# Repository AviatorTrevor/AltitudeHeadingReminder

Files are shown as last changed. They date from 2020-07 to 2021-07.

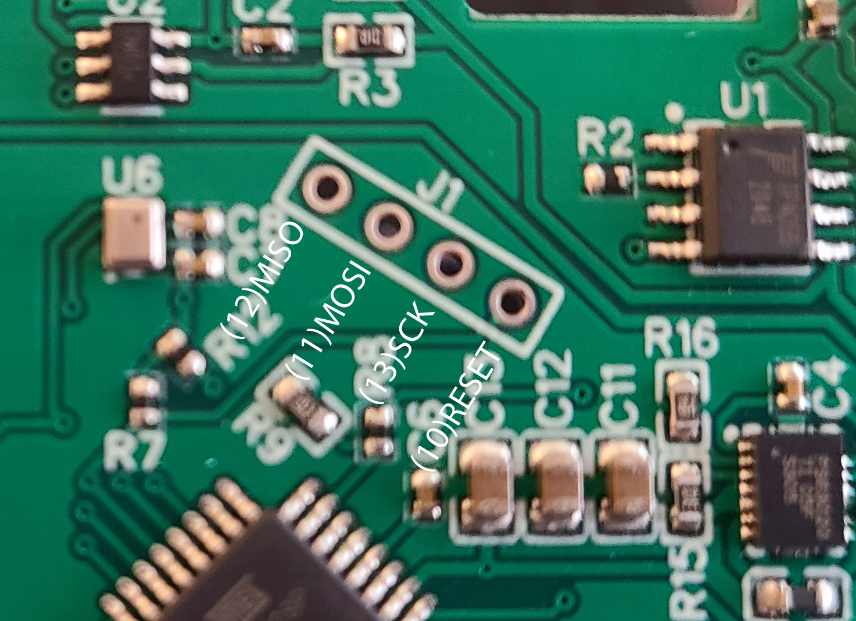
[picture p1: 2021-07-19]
Datasheets and Documents/Bootloader Pins.jpg

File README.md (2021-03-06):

# AltitudeHeadingReminder

Free "EasyEDA" software is needed to view and modify the schematic and PCB design.

Free "openScade" software is needed to view the 3D model of the case

Arduino libraries are modifications of libraries freely found on the web. Those libraries need to be loaded into Arduino in order to compile. The correct type of Arduino and COM port needs to be configured in the Arduino configuration menus before code can be loaded. Because this project runs on a custom PCB board, you need to use the 4 pins on the board for loading a bootloader that has settings to use the onboard 8MHz clock, since there is no external resonator for the clock. Once the bootloader is loaded, you can use the 6-pin FTDI to upload the software using an FTDI adapter.

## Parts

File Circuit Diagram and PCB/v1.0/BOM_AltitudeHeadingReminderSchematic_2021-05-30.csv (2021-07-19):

ID | Name | Designator | Footprint | Quantity | Manufacturer Part | Manufacturer | Supplier | Supplier Part | Price | LCSC Assembly | JLCPCB SMD | Assembly Type | Paste Type
1 | 10uF | C1,C9,C10 | C0402 | 3 | CL05A106MQ5NUNC | SAMSUNG | LCSC | C15525 | 0.0095 | Yes
2 | 100nF | C2,C4,C5,C6,C7,C8 | C0402 | 6 | CL05B104KO5NNNC | SAMSUNG | LCSC | C1525 | 0.0016 | Yes
3 | 22uF | C3,C11,C12,C13,C14,C15,C16 | C0805 | 7 | CL21A226MAQNNNE | SAMSUNG | LCSC | C45783 | 0.038 | Yes
4 | SS34 | D1 | SMA(DO-214AC) | 1 | SS34 |  | LCSC | C8678 | 0.0454
5 | 22uH | L1 | L0805 | 1 | SDFL2012T220KTF | Sunlord | LCSC | C32375 | 0.0343 | Yes
6 | 1.5uH | L2 | L0603 | 1 | MLF1608A1R5JT000 | TDK | LCSC | C87514 | 0.0356 | Yes
7 | FS8205 | Q1 | SOT-23-6 | 1 | FS8205 | FORTUNE | LCSC | C32254 | 0.1688
8 | MMBT3906LT1G | Q2,Q3 | SOT-23-3_L2.9-W1.3-P1.90-LS2.4-BR | 2 | MMBT3906LT1G | ON | LCSC | C53444 | 0.0151 | Yes | Yes | smtWeld | expand
9 | MMBT3904_C181119 | Q4 | SOT-23-3_L2.9-W1.6-P1.90-LS2.8-BR | 1 | MMBT3904 | Hottech | LCSC | C181119 | 0.0101 | Yes | Yes | smtWeld | expand
10 | KT-0603R | R | LED0603-R-RD | 1 | KT-0603R | KENTO | LCSC | C2286 | 0.0059 | Yes
11 | 100 | R3 | R0603 | 1 | 0603WAF1000T5E | UniOhm | LCSC | C22775 | 0.0017 | Yes
12 | 2K | R2,R4 | R0402 | 2 | 0402WGF2001TCE | UniOhm | LCSC | C4109 | 0.0007 | Yes
13 | 39K | R5 | R0402 | 1 | 0402WGF3902TCE | UniOhm | LCSC | C25783 | 0.0008 | Yes
14 | 1K | R1,R6 | R0402 | 2 | 0402WGF1001TCE | UniOhm | LCSC | C11702 | 0.0008 | Yes
15 | 30K | R9 | R0603 | 1 | 0603WAF3002T5E | UniOhm | LCSC | C22984 | 0.0017 | Yes
16 | 10K | R7,R8,R10,R11,R12,R13 | R0402 | 6 | 0402WGF1002TCE | UniOhm | LCSC | C25744 | 0.0008 | Yes
17 | 1M | R15 | R0603 | 1 | 0603WAF1004T5E | UniOhm | LCSC | C22935 | 0.0018 | Yes
18 | 180K | R16 | R0603 | 1 | 0603WAF1803T5E | UniOhm | LCSC | C22827 | 0.0017 | Yes
19 | TP4056 | U1 | ESOP-8_L4.9-W3.9-P1.27-LS6.0-BL-EP | 1 | TP4056 | TOPPOWER | LCSC | C16581 | 0.2164 | Yes
20 | FS312F-G | U2 | SOT-23-6 | 1 | DW01+G | FORTUNE | LCSC | C14213 | 0.1103
21 | MT3608 | U3 | SOT-23-6 | 1 | MT3608 | LCSC | LCSC | C84817 | 0.1423
22 | ATMEGA328P-AU | U5 | TQFP-32_L7.0-W7.0-P0.80-LS9.0-BL | 1 | ATMEGA328P-AU | MICROCHIP | LCSC | C14877 | 5.4962 | Yes
23 | SPL06-001 | U6 | SENSOR-SMD_SPL06-001 | 1 | SPL06-001 | Goertek(歌尔) | LCSC | C2684428 | 0.9605
24 | TPS63020DSJR | U7 | VSON-14_L4.0-W3.0-P0.50-BL | 1 | TPS63020DSJR | TI | LCSC | C15483 | 2.9538 | Yes
25 | TYPEC-304S-ACP16 | USB1 | USB-C-SMD_TYPEC-304S-ACP16 | 1 | TYPEC-304S-ACP16 | XUNPU | LCSC | C720630 | 0.1797 |  |  | smtWeld | expand

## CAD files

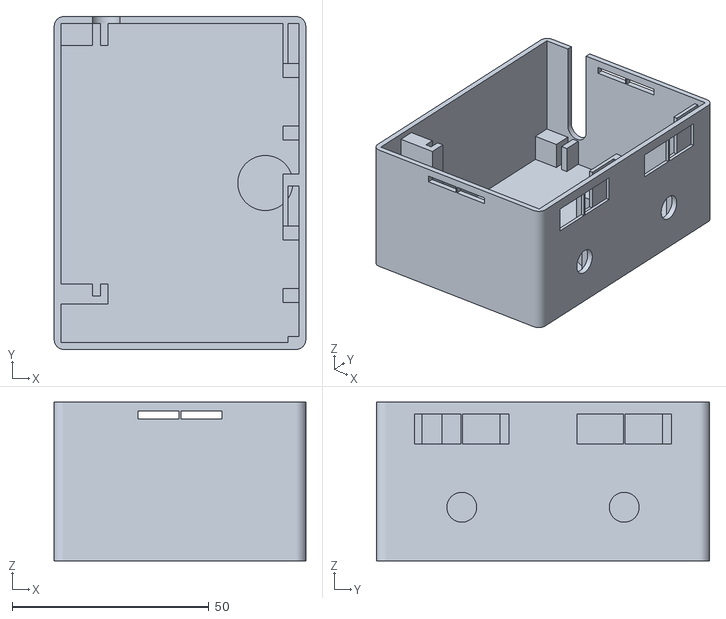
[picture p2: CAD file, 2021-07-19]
Case/Prints/Main.stl
64.0 x 84.7 x 40.4

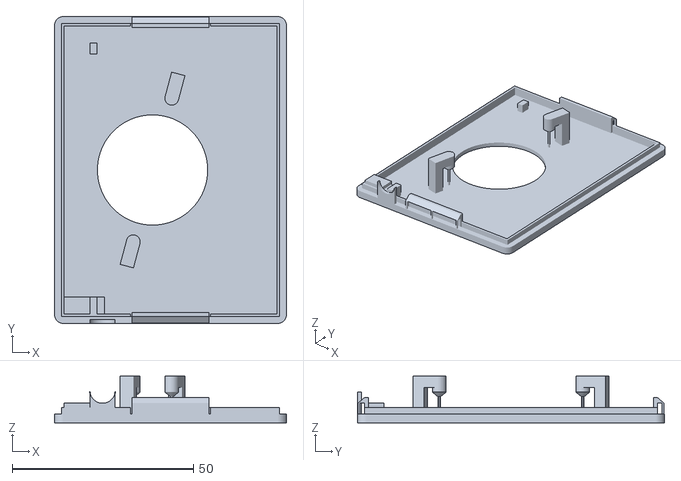
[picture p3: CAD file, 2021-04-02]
Case/Prints/Top.stl
64.0 x 84.7 x 12.8

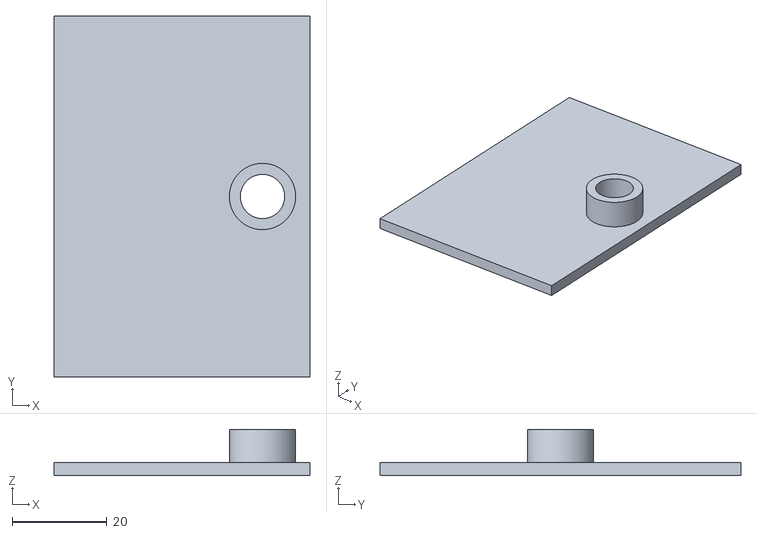
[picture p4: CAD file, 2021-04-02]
Case/Prints/MountingPlate.stl
54.0 x 76.2 x 9.80

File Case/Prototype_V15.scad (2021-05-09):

//everything is in units of millimeters
resolution = 0.35;

//variables to keep in-sync with the other scad file.
pcbBoardHeight = 36.9;
pcbBoardWidth = 69.35;
innerLipHeightAboveOuterLipHeight = resolution * 5;
mainShellThickness = 5 * resolution;
mainDepth = 64;
mainWidth = 84.7;
mainHeight = pcbBoardHeight + mainShellThickness + innerLipHeightAboveOuterLipHeight;
caseCornerRadius = 2.5;
cylinderFragments = 70;

batteryThicknessAndSpacing = 8;
pcbBoardThickness = 2;
pcbMountingWallThickness = 2;
pcbBottomRightWidth = 5.6;
pcbLidTopRightZAxisHeight = 1.2;
pcbOffsetX = mainShellThickness + batteryThicknessAndSpacing;
pcbOffsetY = mainWidth - mainShellThickness - pcbBoardWidth;
pcbBottomRightHeight = 8;
pcbLeftWidth = 3.1;

usbSlotWidth = 7;
usbSlotHeight = 27;
usbSlotXoffset = pcbOffsetX; //offset above mainShellThickness
usbSlotZoffset = 8.5 + usbSlotWidth / 2;

lidThickness = resolution * 4; //z-axis
lidLipWidth = resolution * 2;  //x & y axis thickness of the lip/wall
outerLipHeight = resolution * 5; //height above lidThickness
innerLipHeight = outerLipHeight + innerLipHeightAboveOuterLipHeight; //height above lidThickness
spacingForLidLipFromCaseWall = resolution / 2;
margin = mainShellThickness + lidLipWidth + spacingForLidLipFromCaseWall;
marginFromSnapJointCutaway = resolution;

lidSnapJointProtrusionHeight = 1.5;
lidSnapJointWidth = mainDepth / 3;
lidSnapJointProtrusionLength = mainShellThickness;
lidSnapJointOffsetFromTop = 3;
extensionBeyondOuterLipForSnapJoint = 2;

frontFaceThickness = 3 * resolution;
displayThickness = 3.5; //this is used for the snap-fit mechanism 
displayBackLegThickness = 1.2;
knobAndDisplaySupportWallDepth = displayThickness  - (mainShellThickness - frontFaceThickness) + displayBackLegThickness;

//keep in-sync with the mounting plate file
mountingHoleRadius = 4.5;
mountingQuarterInchRadius = 3.9;
mountingPillarRadius = mountingHoleRadius + 2.5;
mountingHoleHeight = 9.8;
mountingTransitionHeight = 4;
mountingQuarterInchCylinderHeight = mainHeight - mountingHoleHeight - mountingTransitionHeight - 16;
mountingPillarHeight = mainHeight - 14.5;

supportBracketThickness = 0.45;

//////////////////////////////////////////////////////////////////////
//////////////////////////////////////////////////////////////////////
//////////////////////////////////////////////////////////////////////
displayEdgeBuffer = 0.8;
displayWidth = 22.5 + displayEdgeBuffer*2;
displayDepth = mainShellThickness;
displayHeight = 6 + displayEdgeBuffer*2;
displayYOffset = 8.6;
displayIndentWidth = 38.5;
displayIndentHeight = 12.4;
displayIndentYOffsetFromDisplayY = -5.7 - displayEdgeBuffer;
displayIndentZOffsetFromDisplayZ = -2.7 - displayEdgeBuffer;
displayTopOffset = displayIndentHeight + displayIndentZOffsetFromDisplayZ + innerLipHeightAboveOuterLipHeight;
displayPinsYaxisWidth = 2.7;
knobAndDisplaySupportWallWidth = 3.5;
displaySideRetainingPillarThickness = displayThickness - (mainShellThickness - frontFaceThickness);
knobHoleYoffset = displayYOffset + (displayWidth / 2);
knobHoleZoffset = mainShellThickness + 11.9;
knobHoleRadius = 3.8;
knobHoleDepth = mainShellThickness + knobAndDisplaySupportWallDepth;
knobIndentSquareSideLength = 12.4;
knobHookZaxisOffset = 5.1;
knobHookYaxisWidth = 2.2;
knobHookXaxisDepth = knobHoleDepth - resolution*1.5;
knobHookZaxisHeight = 1.7;
gapBetweenTopOfKnobCutoutAndBottomOfDisplayCutout = (mainHeight - displayTopOffset + displayIndentZOffsetFromDisplayZ) - (knobHoleZoffset + knobIndentSquareSideLength/2);
mountingHoleX = mainDepth - mountingPillarRadius - 3.3;


//MODULE snap joint for lid
module createLeftSideLidSnapJoint()
{
  translate([mainDepth/2 - lidSnapJointWidth/2, 0, mainHeight - lidSnapJointOffsetFromTop - lidSnapJointProtrusionHeight + 0.2]) { //NOTE: keep 0.2 in sync
    cube([lidSnapJointWidth, mainShellThickness, lidSnapJointProtrusionHeight + 0.5]);
  };
};

module cutoutLeftKnobStuff() {
  //left knob
  translate([mainDepth - knobHoleDepth, mainWidth/2 - knobHoleYoffset, knobHoleZoffset]) {
    rotate([0,90,0]) {
      cylinder(knobHoleDepth,knobHoleRadius,knobHoleRadius,$fn=cylinderFragments);
    };
  };
  //left knob hook slot
  translate([mainDepth - knobHoleDepth, mainWidth/2 - knobHoleYoffset - knobHookYaxisWidth / 2, knobHoleZoffset - knobHookZaxisOffset - knobHookZaxisHeight]) {
    cube([knobHookXaxisDepth, knobHookYaxisWidth, knobHookZaxisHeight]);
  };
};
module cutoutRightKnobStuff() {
  //right knob
  translate([0,mainWidth,0]) {
    mirror([0,1,0]) {
      cutoutLeftKnobStuff();
    };
  };
};

module cutoutLeftDisplayIndent() {
  //left display indent to make the wall thinner
  translate([mainDepth - displayDepth, mainWidth/2 - displayWidth - displayYOffset + displayIndentYOffsetFromDisplayY, mainHeight - displayTopOffset + displayIndentZOffsetFromDisplayZ]) {
    cube([mainShellThickness - frontFaceThickness, displayIndentWidth, displayIndentHeight]);
  };
  //extra cutout for pins
  translate([mainDepth - displayDepth, mainWidth/2 - displayWidth - displayYOffset + displayIndentYOffsetFromDisplayY, mainHeight - displayTopOffset + displayIndentZOffsetFromDisplayZ]) {
    cube([mainShellThickness - resolution*1.5, displayPinsYaxisWidth, displayIndentHeight]);
  };
};

module cutoutRightDisplayIndent() {
  //right display indent to make the wall thinner
  translate([mainDepth - displayDepth, mainWidth/2 + displayYOffset + displayIndentYOffsetFromDisplayY, mainHeight - displayTopOffset + displayIndentZOffsetFromDisplayZ]) {
    cube([mainShellThickness - frontFaceThickness, displayIndentWidth, displayIndentHeight]);
  };
  //extra cutout for pins
  translate([mainDepth - displayDepth, mainWidth/2 + displayYOffset + displayIndentYOffsetFromDisplayY, mainHeight - displayTopOffset + displayIndentZOffsetFromDisplayZ]) {
    cube([mainShellThickness - resolution*1.5, displayPinsYaxisWidth, displayIndentHeight]);
  };
};
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

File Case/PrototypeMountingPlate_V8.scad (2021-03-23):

//everything is in units of millimeters
resolution = 0.35;

//variables to keep in-sync with the other scad file
mainShellThickness = 5 * resolution;
mainDepth = 57;
mainWidth = 91;
mainHeight = 37 + mainShellThickness;
caseCornerRadius = 2.5;
cylinderFragments = 70;

//keep in-sync with the main case file
mountingHoleRadius = 4.45;
mountingPillarRadius = mountingHoleRadius + 1.5;
mountingHoleHeight = 8.68;
mountingPillarHeight = mountingHoleHeight + 0.5;

plateDepth = mainDepth / 1.5;
plateWidth = mainWidth / 1.5;
plateThickness = mountingPillarHeight;
plateHoleRadius = mountingHoleRadius + resolution / 2;
plateMountingHoleX = plateDepth - plateThickness - mountingHoleRadius - 3.3; //keep aligned with mountingHoleX variable

difference() {
    cube([plateDepth, plateWidth, plateThickness]);
    
    //bottom mounting hole
    translate([plateMountingHoleX, plateWidth/2, 0]) {
      cylinder(plateThickness, plateHoleRadius, plateHoleRadius, $fn=cylinderFragments);
    };
};

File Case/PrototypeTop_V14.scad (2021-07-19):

//everything is in units of millimeters
resolution = 0.35;

//variables to keep in-sync with the other scad file
pcbBoardHeight = 36.9;
pcbBoardWidth = 69.35;
innerLipHeightAboveOuterLipHeight = resolution * 5;
mainShellThickness = 5 * resolution;
mainDepth = 64;
mainWidth = 84.7;
mainHeight = pcbBoardHeight + mainShellThickness + innerLipHeightAboveOuterLipHeight;
caseCornerRadius = 2.5;
cylinderFragments = 70;

batteryThicknessAndSpacing = 8;
pcbBoardThickness = 2;
pcbMountingWallThickness = 2;
pcbBottomRightWidth = 5.6;
pcbLidTopRightZAxisHeight = 1.2;
pcbOffsetX = mainShellThickness + batteryThicknessAndSpacing;
pcbOffsetY = mainWidth - mainShellThickness - pcbBoardWidth;
pcbBottomRightHeight = 8;
pcbLeftWidth = 3.1;

usbSlotWidth = 7;
usbSlotHeight = 27;
usbSlotXoffset = pcbOffsetX; //offset above mainShellThickness
usbSlotZoffset = 8.5 + usbSlotWidth / 2;

lidThickness = resolution * 4; //z-axis
lidLipWidth = resolution * 2;  //x & y axis thickness of the lip/wall
outerLipHeight = resolution * 3; //height above lidThickness
innerLipHeight = outerLipHeight + innerLipHeightAboveOuterLipHeight; //height above lidThickness
spacingForLidLipFromCaseWall = resolution / 2;
margin = mainShellThickness + lidLipWidth + spacingForLidLipFromCaseWall;
marginFromSnapJointCutaway = resolution;

lidSnapJointProtrusionHeight = 1.5;
lidSnapJointWidth = mainDepth / 3;
lidSnapJointProtrusionLength = mainShellThickness;
lidSnapJointOffsetFromTop = 3;
extensionBeyondOuterLipForSnapJoint = 2;

frontFaceThickness = 3 * resolution;
displayThickness = 3.5; //this is used for the snap-fit mechanism 
displayBackLegThickness = 1.2;
knobAndDisplaySupportWallDepth = displayThickness  - (mainShellThickness - frontFaceThickness) + displayBackLegThickness;

lidSnapJointHingeThickness = outerLipHeight * 0.4; //has to be quite a bit smaller than outerLipHeight
lidSnapJointLegThickness = resolution * 3;
lidSnapJointCutoutGapFromEdge = resolution * 2;

outerLipWidth = mainShellThickness + spacingForLidLipFromCaseWall;

//////////////////////////////////////////////////////////////////////
//////////////////////////////////////////////////////////////////////
//////////////////////////////////////////////////////////////////////

buzzerRadius = 30.4 / 2; //30.4 is diameter
buzzerScrewOffset = 20.5; //20.5 mm from center of buzzer hole to center of screw hole
buzzerScrewRadius = 1.9;
buzzerX = pcbOffsetX + pcbBoardThickness + buzzerRadius + 0.1;
buzzerY = mainWidth / 2;
buzzerScrewHeight = 5;
buzzerScrewHeightForBaseHolding = 2.5;
buzzerPlatformOffset = 3.8; //offset from center of cylinder to edge of wall to clear the buzzer
buzzerPlatformThickness = 9 * resolution;
buzzerScrewPylonZOffset = -0.8; //distance from the lid to fit the buzzer into the slot

screwHeadCylinderRadius = 1.8;
screwHeadSinkDepth = lidThickness * 0.6;

snapHook3dPrintingSupportPillarThickness = resolution * 1.4;
buzzer3dPrintingSupportPillarThicknessRadius = resolution * 0.9;

module rotate_about_pt(z, y, pt) {
    translate(pt)
        rotate([0, y, z])
            translate(-pt)
                children();   
}

module innerCube() {
  translate([margin, margin, lidThickness]) {
    cube([mainDepth - margin*2, mainWidth - margin*2, innerLipHeight]);
  };
};

module cutOutLeftSideForHinge() {
  //cut away the inner wall for left side snap fit stuff + buffer on either side
  translate([mainDepth/2 - lidSnapJointWidth/2 - marginFromSnapJointCutaway, outerLipWidth, lidThickness]) {
    cube([lidSnapJointWidth + marginFromSnapJointCutaway*2, lidLipWidth, innerLipHeight]);
  };
};

module leftBuzzerPlatform() {
  translate([buzzerX, buzzerY - buzzerScrewOffset, lidThickness + buzzerScrewHeight - buzzerScrewPylonZOffset]) {
    cylinder(buzzerScrewHeightForBaseHolding/2, buzzerScrewRadius * 0.2, buzzerScrewRadius, $fn=cylinderFragments);
  };
  translate([buzzerX, buzzerY - buzzerScrewOffset, lidThickness + buzzerScrewHeight + buzzerScrewHeightForBaseHolding/2 - buzzerScrewPylonZOffset]) {
    cylinder(buzzerScrewHeightForBaseHolding/2 + buzzerPlatformThickness, buzzerScrewRadius, buzzerScrewRadius, $fn=cylinderFragments);
  };
  //3D printed support for screw mount
  translate([buzzerX, buzzerY - buzzerScrewOffset, lidThickness]) {
    cylinder(buzzerScrewHeight - buzzerScrewPylonZOffset, buzzer3dPrintingSupportPillarThicknessRadius, buzzer3dPrintingSupportPillarThicknessRadius, $fn=cylinderFragments);
  };
  
  //horizontal platform to hold buzzer
  translate([buzzerX - buzzerScrewRadius, buzzerY - buzzerScrewOffset - buzzerPlatformOffset - buzzerPlatformThickness, lidThickness + buzzerScrewHeight + buzzerScrewHeightForBaseHolding - buzzerScrewPylonZOffset]) {
    cube([2*buzzerScrewRadius, buzzerPlatformOffset + buzzerPlatformThickness,buzzerPlatformThickness]);
  };
  //vertical platform to mount the horizontal platform
  translate([buzzerX - buzzerScrewRadius, buzzerY - buzzerScrewOffset - buzzerPlatformOffset - buzzerPlatformThickness, lidThickness]) {
    cube([2*buzzerScrewRadius, buzzerPlatformThickness, buzzerScrewHeight + buzzerScrewHeightForBaseHolding - buzzerScrewPylonZOffset]);
  };
};

difference() {
  union() {
    //top cover of the lid
    cube([mainDepth, mainWidth, lidThickness]);
      
    //outer lip
    difference() {
      translate([0, 0, lidThickness]) {
        cube([mainDepth, mainWidth, outerLipHeight]);
      };
      translate([outerLipWidth, outerLipWidth, lidThickness]) {
        cube([mainDepth - outerLipWidth*2, mainWidth - outerLipWidth*2, outerLipHeight]);
      };
    };
    
    //add rails for better seating
    difference() {
      translate([margin - lidLipWidth, margin - lidLipWidth, lidThickness]) {
        cube([mainDepth - margin*2 + lidLipWidth*2, mainWidth - margin*2 + lidLipWidth*2, innerLipHeight]);
      };
      innerCube();
    };
  };

  //cutting out the inside to save on plastic used
  innerCube();
  
  //cutting away room at the corner of the lip to make room for the cylinders where screws go.
  //rear-left
  translate([0, 0, 0]) {
    cube([caseCornerRadius, caseCornerRadius, lidThickness + outerLipHeight]);
  };
  
  //cutting away room at the corner of the lip to make room for the cylinders where screws go.
  //front-left
  translate([mainDepth - caseCornerRadius, 0, 0]) {
    cube([caseCornerRadius, caseCornerRadius, lidThickness + outerLipHeight]);
  };
  
  //cutting away room at the corner of the lip to make room for the cylinders where screws go.
  //front-right
  translate([mainDepth - caseCornerRadius, mainWidth - caseCornerRadius, 0]) {
    cube([caseCornerRadius, caseCornerRadius, lidThickness + outerLipHeight]);
  };
  
  //cutting away room at the corner of the lip to make room for the cylinders where screws go.
  //rear-right
  translate([0, mainWidth - caseCornerRadius, 0]) {
    cube([caseCornerRadius, caseCornerRadius, lidThickness + outerLipHeight]);
  };
  
  //buzzer alarm hole
  translate([buzzerX, buzzerY, 0]) {
    cylinder(lidThickness, buzzerRadius, buzzerRadius, $fn=cylinderFragments*2);
  };
  
  cutOutLeftSideForHinge();
  translate([0,mainWidth - 0.001,0]) {
    mirror([0,1,0]) {
      cutOutLeftSideForHinge();
    };
  };
};

module snapHook3dPrintingSupportPillarBeneathProtrusion() {
  cube([snapHook3dPrintingSupportPillarThickness, snapHook3dPrintingSupportPillarThickness, lidSnapJointOffsetFromTop]);
};
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

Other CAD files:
Case/Prototype_V1.scad
Case/Old Designs/PrototypeMountingPlate_V1.scad
Case/Old Designs/PrototypeMountingPlate_V2.scad
Case/Old Designs/PrototypeTop_V1.scad
Case/Old Designs/PrototypeTop_V10.scad
Case/Old Designs/PrototypeTop_V11.scad
Case/Old Designs/PrototypeTop_V12.scad
Case/Old Designs/PrototypeTop_V13.scad
Case/Old Designs/PrototypeTop_V2.scad
Case/Old Designs/PrototypeTop_V3.scad
Case/Old Designs/PrototypeTop_V4.scad
Case/Old Designs/PrototypeTop_V5.scad
Case/Old Designs/PrototypeTop_V6.scad
Case/Old Designs/PrototypeTop_V7.scad
Case/Old Designs/PrototypeTop_V8.scad
Case/Old Designs/PrototypeTop_V9.scad
Case/Old Designs/Prototype_V1.scad
Case/Old Designs/Prototype_V10.scad
Case/Old Designs/Prototype_V11.scad
Case/Old Designs/Prototype_V12.scad
Case/Old Designs/Prototype_V13.scad
Case/Old Designs/Prototype_V14.scad
Case/Old Designs/Prototype_V2.scad
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

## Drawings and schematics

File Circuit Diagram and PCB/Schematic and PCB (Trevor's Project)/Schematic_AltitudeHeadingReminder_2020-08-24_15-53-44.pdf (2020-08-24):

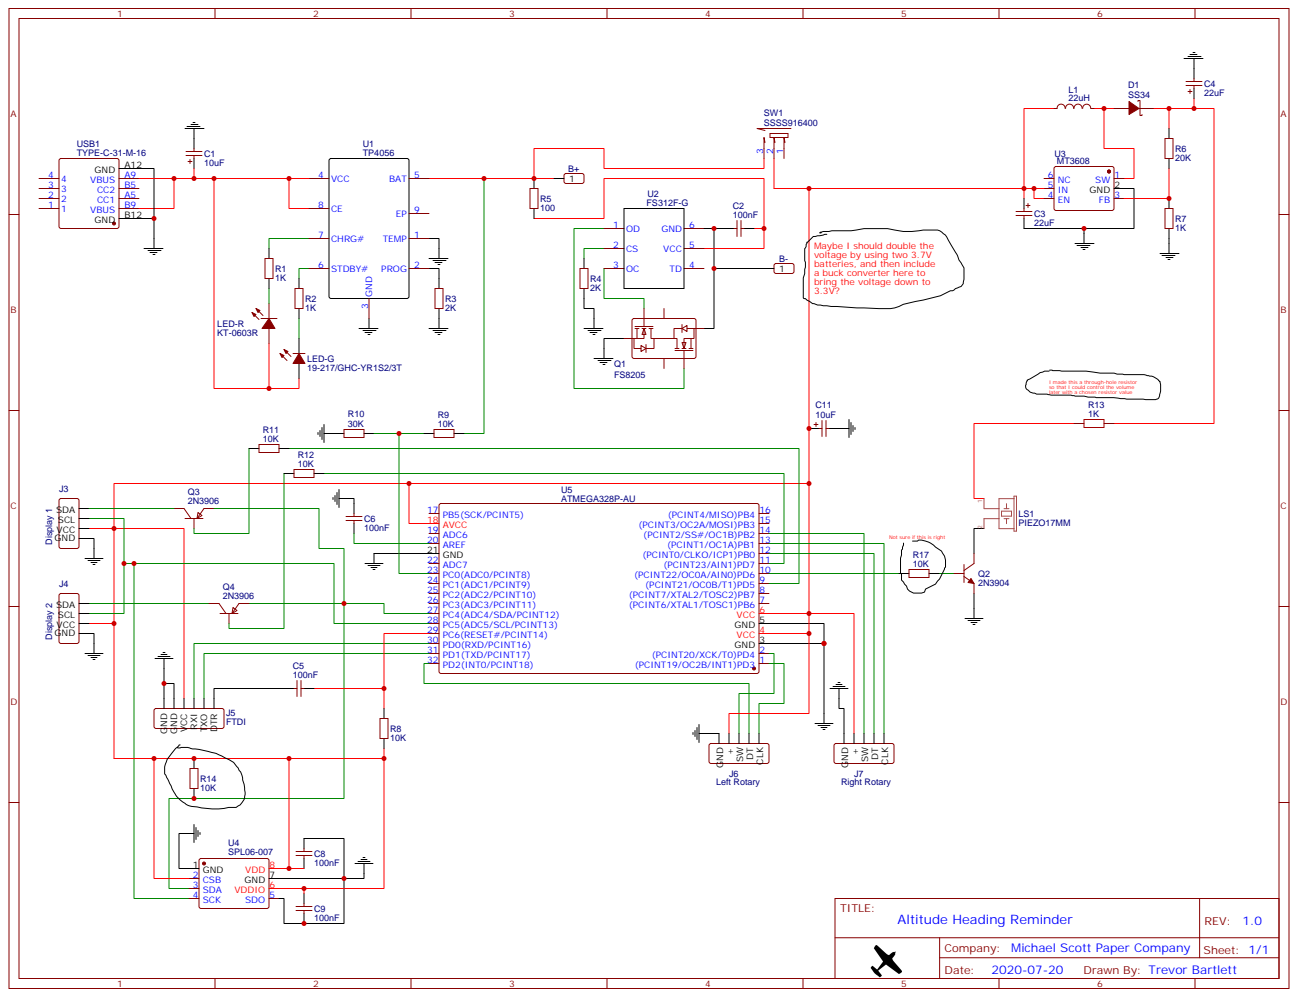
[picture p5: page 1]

Maybe I should double the
voltage by using two 3.7V

batteries, and then include
a buck converter here to
bring the voltage down to

I made this a through-hole resistor
so that I could control the volume
later with a chosen resistor value

Not sure if this is right

Company: Michael Scott Paper Company

Drawn By: Trevor Bartlett

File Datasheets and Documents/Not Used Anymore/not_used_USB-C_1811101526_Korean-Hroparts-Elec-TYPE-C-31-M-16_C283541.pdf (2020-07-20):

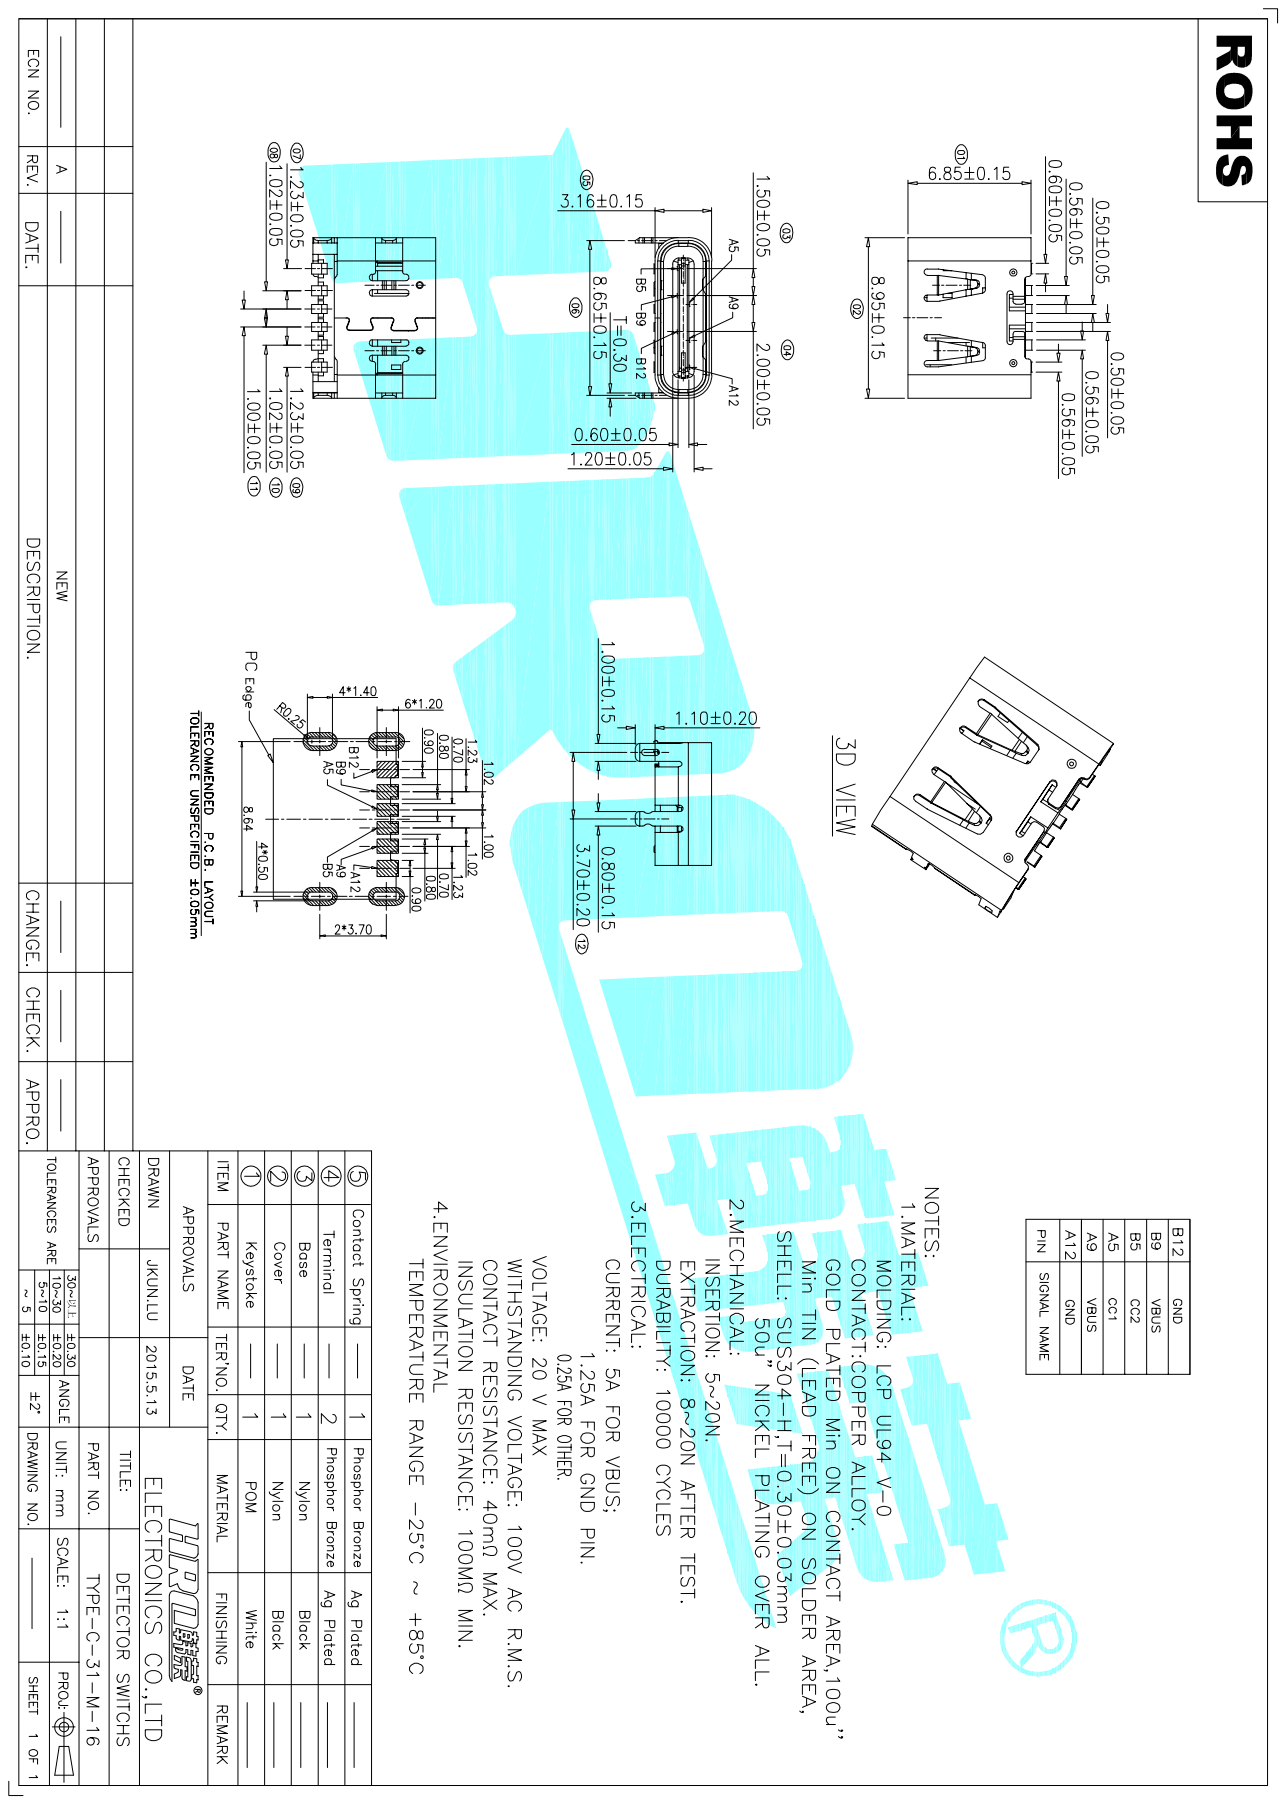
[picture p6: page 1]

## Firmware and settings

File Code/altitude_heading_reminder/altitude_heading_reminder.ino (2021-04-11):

/*
Author: Trevor Bartlett
Email: aviatortrevor@gmail.com

Hardware device to remind pilots of assigned headings, altitudes, IFR procedure minimums, and other features.
The device measures atmospheric pressure to present to the pilot what their altitude is. Cabin altitude can
be slightly different from static pressure used by the aircraft's altimeter, so there is a calibration offset
provided to the user. It also has buzzer feature to alert the pilot of when he/she is approaching their
selected altitude, or departed from it.

*TODO:
*add adjustable altitude-deviation alert?
*create software license - credit for libraries used
*     https://forum.arduino.cc/index.php?topic=175511.0
*     http://www.engblaze.com/microcontroller-tutorial-avr-and-arduino-timer-interrupts/
*     https://learn.adafruit.com/adafruit-gfx-graphics-library/using-fonts
*/
#include <EEPROM.h>
#include <SPL06-007.h>
#include <Wire.h>
#include <Custom_GFX.h>
#include <Custom_SSD1306.h>

#define cAppCodeNumberOfDigits         6
#define cAppCodeOne                    8
#define cAppCodeTwo                    8
#define cAppCodeThree                  1
#define cAppCodeFour                   6
#define cAppCodeFive                   6
#define cAppCodeSix                    6
#define cOneSecond                     1000 //1000 milliseconds = 1 second
#define cOneSecondBeforeOverflow       (unsigned long)(pow(2, sizeof(unsigned long) * 8) - cOneSecond)
#define cTenSeconds                    10000
#define cLeftRotaryTimeoutSeconds      cTenSeconds
#define cFeetInMeters                  3.28084
#define cSeaLevelPressureHPa           1013.25 //standard sea level pressure in millibars
#define cMbInHg                        33.8639
#define cSeaLevelPressureInHg          2992 //standard sea level pressure in inches of mercury (x100)
#define cSeaLevelPressureInHgDouble    29.92
#define cFtLabel                       "ft"
#define cInLabel                       "\""
#define cDegFLabel                     'F'
#define cAltitudeSelectIncrement       100   //ft
#define cAltitudeFineSelectIncrement   10    //ft
#define cAltitudeHighSelectIncrement   1000  //ft
#define cMinimumsSelectIncrement       50    //ft
#define cHighAltitude                  18000 //ft
#define cDefaultSelectedAltitude       10000 //ft
#define cDefaultMinimumsAltitude       1000  //ft
#define cLowestAltitudeSelect          -1000 //ft
#define cHighestAltitudeSelect         60000 //ft
#define cHighestAltitudeAlert          24000 //ft, the pressure sensor will only measure so high. No point in alerting above a certain pressure level
#define cAltimeterSettingInHgMin       2750  //inHg * 100
#define cAltimeterSettingInHgMax       3150  //inHg * 100
#define cAltimeterSettingInHgInterval  1     //inHg
#define cCalibrationOffsetMin          -5000 //ft
#define cCalibrationOffsetMax          5000  //ft
#define cCalibrationOffsetInterval     10    //ft
#define cHeadingSelectIncrement        5     //degrees
#define cDefaultSelectedHeading        360   //degrees
#define cTrueAltitudeRoundToNearestFt  10    //ft

//EEPROM
#define         cSizeOfEeprom                       EEPROM.length() //1024
#define         cEepromWriteDelay                   1200  //milliseconds
#define         cEepromMaxWrites                    100000
#define         cEepromNextAvailableSlot            12
#define         cEepromAltimeterAddr                14
#define         cEepromAltitudeOffsetAddr           16
#define         cEepromPermanentAltitutdeOffsetAddr 18
#define         cEepromSensorModeAddr               20
#define         cEepromScreenDimAddr                22
#define         cEepromScreenOrientationAddr        24
#define         cEepromSelectedAltitudeAddr         26
#define         cEepromSelectedHeadingAddr          28
#define         cEepromSelectedMinimumsAddr         30
#define         cEepromLastAddr                     cEepromSelectedMinimumsAddr
volatile bool   gNeedToWriteToEeprom;

//SPL06-007 Sensor variables
#define    cSensorLoopCycle               2 //2Hz
#define    cSensorLoopPeriod              (cOneSecond / cSensorLoopCycle)
double     gSensorTemperatureDouble;      //farhenheit
enum SensorMode {SensorModeOff, SensorModeSilent, SensorModeOnHide, SensorModeOnShow, cNumberOfSensorModes};
volatile SensorMode gSensorMode;

//Main program variables
double          gTrueAltitudeDouble;
volatile long   gSelectedAltitudeLong;
volatile int    gAltimeterSettingInHgInt;
volatile int    gCalibratedAltitudeOffsetInt;
volatile int    gPermanentCalibratedAltitudeOffsetInt;
volatile int    gSelectedHeadingInt; //degrees
volatile bool   gMinimumsOn;
volatile long   gMinimumsAltitudeLong;
volatile bool   gMinimumsTriggered = true;
volatile bool   gMinimumsSilenced = true;

//Anti-piracy
volatile int    gSelectAppCode = 0;
volatile int    gAppCodeSequence = 0;
bool            gLegitimate = true;

//Buzzer
#define            cAlarm200ToGo                         200  //ft
#define            cAlarm1000ToGo                        1000 //ft
#define            cBuzzPin                              6
#define            cLongBuzzDuration                     1000
#define            cShortBuzzOnDuration                  250
#define            cShortBuzzOffDuration                 100
#define            cMinimumsLongBuzzOnDuration           375
#define            cMinimumsShortBuzzOnDuration          125
#define            cMinimumsBuzzOffDuration              125
#define            cMinimumsOffBetweenCycleDuration      125
#define            cMinimumsNumberOfBeepCylces           5
#define            cUrgentBuzzNumberOfBeeps              3
#define            cDisableAlarmKnobMovementTime         1200
#define            cDisableAlarmAfterAlarmTime           1800
enum BuzzAlarmMode {Climbing1000ToGo, Climbing200ToGo, Descending1000ToGo, Descending200ToGo, AltitudeDeviate, UrgentAlarm, MinimumsAlarm, LongAlarm, AlarmDisabled, DetermineAlarmState};
BuzzAlarmMode      gAlarmModeEnum = AlarmDisabled;
int                gBuzzCountInt;
int                cPowerUpSilence = 7000; //wait 7 seconds after start-up before alarm can begin making sounds. this is so you don't scare anyone with a loud alarm as soon as they start it up at home.

//Minimums
#define            cMinimumsSilencedAutoOnAltitudeDiff   100 //ft
#define            cMinimumsTriggeredAutoOffTime         30000 //30 seconds

//Top-left corner message for low battery or silent mode
#define       cAltMessageInterval 15000 //15 seconds
#define       cAltMessageDuration 1500  //1.5 seconds

//Battery
#define       cBatteryVoltagePin      A0
#define       cBatteryUpdateInterval  3000 //once per 3 seconds
#define       cBatteryAlertLevel      15
int           gBatteryLevel;
bool          gBatteryCharging;
unsigned long gBatteryUpdateTs;
#define       cBatteryCapacityArrayLength   21
#define       cBatteryCapacityArrayInterval 5 //this represents the jump in battery capacity per index in the array
const double  cBatteryCapacity[2][cBatteryCapacityArrayLength] = {
  2.40, 3.41, 3.48, 3.54, 3.58, 3.62, 3.67, 3.71, 3.76, 3.79, 3.82, 3.84, 3.87, 3.91, 3.94, 3.98, 4.01, 4.03, 4.06, 4.09, 4.15,
     0,    5,   10,   15,   20,   25,   30,   35,   40,   45,   50,   55,   60,   65,   70,   75,   80,   85,   90,   95,  100
};

//Timing control
unsigned long          gNextSensorReadyTs;
unsigned long          gNextBuzzTs;
unsigned long          gLastAlarmTs; //this value disables the alarm temporarily just at start-up so people's ears aren't blown when they power it on.
unsigned long          gTimerStartTs;
unsigned long          gMinimumsTriggeredTs;
volatile unsigned long gLeftButtonPressedTs;
volatile unsigned long gRightButtonPressedTs;
volatile unsigned long gLastRightRotaryActionTs;
volatile unsigned long gLastMinimumsAltitudeTs;
volatile unsigned long gLeftRotaryReleaseTs;
volatile unsigned long gRightRotaryReleaseTs;
volatile unsigned long gEepromSaveNeededTs;
volatile unsigned long gLastRotaryActionTs;

//Display
#define cPinLeftDisplayControl  5
#define cPinRightDisplayControl 7
#define CONTROL_ON       LOW
#define CONTROL_OFF      HIGH
#define cOledAddr        0x3C
#define cOledWidth       128
#define cOledHeight      32
#define cOledReset       4
#define cLabelTextSize   1
#define cLabelTextYpos   1
#define cReadoutTextSize 3
#define cReadoutTextYpos 10
Custom_SSD1306 gOled(cOledWidth, cOledHeight, &Wire, cOledReset);
volatile bool gOledDim = false;
volatile bool gDeviceFlipped = false;
volatile bool gUpdateLeftScreen = true;
volatile bool gUpdateRightScreen = true;
bool gFlashLeftScreen = false;
bool gFlashRightScreen = false;

char gDisplayTopContent[20];
char gDisplayBottomContent[10];

//Cursor control
enum Cursor {
    CursorSelectHeading,
    CursorSelectAltimeter,
    CursorSelectMinimumsOn,
    CursorSelectMinimumsAltitude,
    CursorSelectTimer,
    CursorSelectBrightness, //starting here, values won't stay on the screen for more than a few seconds unless there is a rotary action
    CursorSelectOffset,
    CursorSelectSensor,
    CursorSelectFlipDevice,
    CursorViewSensorTemp,
    CursorViewAltitude,
    CursorViewBatteryLevel,
    cNumberOfCursorModes }
    gCursor = CursorSelectHeading;

//Rotary Knobs
#define cRotaryStates              4
#define cDtLookup                  0 //row 0 in cEncoderValues matrix lookup
#define cClkLookup                 1 //row 1 in cEncoderValues matrix lookup
#define cLongRightButtonPress      1500
#define cLongLeftButtonPress       1000
#define cRotaryButtonReleaseDelay  60
#define PRESSED                    LOW
#define RELEASED                   HIGH


//Rotary encoder signal pairs, DT CLK - clockwise order
//When DT & CLK are both 1, the rotary is sitting on a detent
const int cEncoderValues[2][cRotaryStates] = {
  1, 1, 0, 0, //DT
  1, 0, 0, 1  //CLK
};

//Right Rotary Knob
#define        cPinRightRotarySignalDt  8
#define        cPinRightRotarySignalClk 9
#define        cPinRightRotaryButton    10
volatile int   gRightRotaryIndex;
volatile int   gRightRotaryButton = RELEASED;
volatile int   gRightRotaryButtonPreviousValue = RELEASED;
volatile int   gRightRotaryDirection;
volatile bool  gRightButtonPossibleLongPress;
volatile bool  gRightRotaryFineTuningPress;
volatile bool  gDisableRightRotaryProcessing; //we disable knob processing right after the altitude-sync command until the button is released

//Left Rotary Knob
#define        cPinLeftRotarySignalDt  2
#define        cPinLeftRotarySignalClk 3
#define        cPinLeftRotaryButton    4
volatile int   gLeftRotaryIndex;
volatile int   gLeftRotaryButton = RELEASED;
volatile int   gLeftRotaryButtonPreviousValue = RELEASED;
volatile int   gLeftRotaryDirection;
volatile bool  gLeftButtonPossibleLongPress;
volatile bool  gLeftRotaryFineTuningPress;
volatile bool  gDisableLeftRotaryProcessing; //we disable knob processing right after the screen changes pages until the button is released

//////////////////////////////////////////////////////////////////////////
void setup() {
  #ifdef DEBUG
  Serial.begin(9600);
  #endif
  initializeDisplayDevice();
  initializeRotaryKnobs();
  initializePiracyCheck();
  initializeValuesFromEeprom();
  initializePressureSensor();
  initializeBuzzer();
  gBatteryLevel = getBatteryLevel();
}
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
void loop() {
  if (millis() > cOneSecondBeforeOverflow) { //this handles the extremely rare case (every ~50 days of uptime) that the clock overflows
    gNextSensorReadyTs = gNextBuzzTs = 0; //reset timing
    delay(cOneSecond); //we take a 1 second frozen penalty for handling this extremely rare situation
    return; //return so that we grab a new currentTime
  }

  if (millis() >= gNextSensorReadyTs) {
    handlePressureSensor();
  }

  //check & handle long-press of left rotary knob
  if (gLeftButtonPossibleLongPress && millis() - gLeftButtonPressedTs >= cLongLeftButtonPress) {
    handleLeftRotaryLongPress();
  }

  //check & handle long-press of right rotary knob
  if (gRightButtonPossibleLongPress && millis() - gRightButtonPressedTs >= cLongRightButtonPress) {
    handleRightRotaryLongPress();
  }

  //if the left screen has been inactive for too long on a non-priority screen, go back to the heading screen
  /*TODO: debug?
  if (gCursor > CursorSelectTimer && millis() - gLastRotaryActionTs >= cLeftRotaryTimeoutSeconds) {
    gCursor = CursorSelectHeading;
    gUpdateLeftScreen = true;
  }*/

  //Update battery level
  if (millis() - gBatteryUpdateTs >= cBatteryUpdateInterval) {
    updateBatteryLevel();
  }

  //Automatically turn off minimums if these conditions are met
  if (gMinimumsTriggered && millis() - gMinimumsTriggeredTs >= cMinimumsTriggeredAutoOffTime) {
    gMinimumsOn = false;
    if (gCursor == CursorSelectMinimumsOn || gCursor == CursorSelectMinimumsAltitude) {
      gUpdateLeftScreen = true;
      gCursor = CursorSelectMinimumsOn; //kick us back to this mode, because the "MinimumsAltitude" always says "ON"
    }
    gUpdateRightScreen = true;
  }

  handleBuzzer();
  handleDisplay();

  if (gNeedToWriteToEeprom && millis() - gEepromSaveNeededTs >= cEepromWriteDelay) {
    writeValuesToEeprom();
  }
}

//////////////////////////////////////////////////////////////////////////
void handlePressureSensor() {
  gNextSensorReadyTs = millis() + cSensorLoopPeriod;

  //get temperature
  gSensorTemperatureDouble = get_temp_f();
  if (gCursor == CursorViewSensorTemp || gCursor == CursorViewAltitude) {
     gUpdateLeftScreen = true;
  }

  if (gSensorMode != SensorModeOff) {
    //get altitude
    gTrueAltitudeDouble = altitudeCorrected(cFeetInMeters * get_altitude(get_pressure(), cSeaLevelPressureHPa));
    if (gMinimumsSilenced && gTrueAltitudeDouble - gMinimumsAltitudeLong >= cMinimumsSilencedAutoOnAltitudeDiff) {
      gMinimumsSilenced = false;
    }
    gUpdateRightScreen = true;
  }
}

//////////////////////////////////////////////////////////////////////////
void handleLeftRotary(int rotaryButton, int rotaryDt, int rotaryClk) {
  //The button being pressed can lead to 1 of 3 outcomes: {Short Press, Long Press, a rotation occuring before the long press time is reached}
  gLeftRotaryButton = digitalRead(rotaryButton); //read button state
  int leftRotaryDt = digitalRead(rotaryDt);
  int leftRotaryClk = digitalRead(rotaryClk);

  if (!gLegitimate) {
    if (gLeftRotaryButton == PRESSED && gSelectAppCode != 0) {
      gAppCodeSequence++;
    }
  }
  else {
    gLastRotaryActionTs = millis();
  
    if (gLeftRotaryButton != gLeftRotaryButtonPreviousValue && millis() - gLeftRotaryReleaseTs >= cRotaryButtonReleaseDelay) { //if button state changed
      gLeftRotaryButtonPreviousValue = gLeftRotaryButton;
      if (gLeftRotaryButton == PRESSED) {
        gLeftButtonPressedTs = millis();
        gLeftButtonPossibleLongPress = true;
        gLeftRotaryFineTuningPress = false;
      }
      else if (millis() - gLeftButtonPressedTs < cLongLeftButtonPress && !gLeftRotaryFineTuningPress) { //released after short press that wasn't a fine-tuning event
        gLeftButtonPossibleLongPress = false;
        gLeftRotaryReleaseTs = millis();
        handleLeftRotaryShortPress();
      }
      else { //(gLeftRotaryButton == RELEASED) //released after either a long-press or a fine-tuning press
        gLeftButtonPossibleLongPress = false;
        gDisableLeftRotaryProcessing = false;
        gLeftRotaryReleaseTs = millis();
      }
    }
  }
  
  //Handle rotation
  int clockwiseRotationIndex = (gLeftRotaryIndex + 1) % cRotaryStates;
  int counterclockwiseRotationIndexIndex = (gLeftRotaryIndex - 1 + cRotaryStates) % cRotaryStates;
  if (leftRotaryDt == cEncoderValues[cDtLookup][clockwiseRotationIndex] && leftRotaryClk == cEncoderValues[cClkLookup][clockwiseRotationIndex]) {
    gLeftRotaryDirection++;
    gLeftRotaryIndex = clockwiseRotationIndex;
  }
  else if (leftRotaryDt == cEncoderValues[cDtLookup][counterclockwiseRotationIndexIndex]
        && leftRotaryClk == cEncoderValues[cClkLookup][counterclockwiseRotationIndexIndex]) {
    gLeftRotaryDirection--;
    gLeftRotaryIndex = counterclockwiseRotationIndexIndex;
  }

  if (gLeftRotaryIndex == 0) { //if we reached a detent on the rotary (gLeftRotaryIndex == 0)
    //either we moved clockwise, counter-clockwise, or wiggled a little back without hitting a neighboring detent
    handleLeftRotaryMovement(gLeftRotaryDirection / cRotaryStates);
    gLeftRotaryDirection = 0;
  }
}

//////////////////////////////////////////////////////////////////////////
void handleLeftRotaryMovement(int increment) {
  if (increment == 0 || gDisableLeftRotaryProcessing) {
    return; //if we didn't really move detents, do nothing
  }
  gUpdateLeftScreen = true;

  if (!gLegitimate) {
    gSelectAppCode += increment;
    return;
  }
  
  gLeftButtonPossibleLongPress = false;
  gLeftRotaryFineTuningPress = (gLeftRotaryButton == PRESSED); //not all states have a fine-tuning press, but we still have to set this here because we don't want a short-press to register and move cursor

  switch (gCursor) {
    case CursorSelectHeading:
    {
      if (gLeftRotaryFineTuningPress) {
        gSelectedHeadingInt = (gSelectedHeadingInt + increment + 359) % 360 + 1;
      }
      else {
        int incrementMagnitude = cHeadingSelectIncrement;
        if (gSelectedHeadingInt % cHeadingSelectIncrement != 0) {
          incrementMagnitude = cHeadingSelectIncrement / 2; //we are at an in-between cHeadingSelectIncrement state, so the knob movement will increment or decement to the nearest cHeadingSelectIncrement
        }
        gSelectedHeadingInt = (roundNumber((gSelectedHeadingInt + increment * incrementMagnitude), cHeadingSelectIncrement) + 359) % 360 + 1;
      }
      gEepromSaveNeededTs = millis();
      gNeedToWriteToEeprom = true; //save heading to EEPROM
      break;
    }
    
    case CursorSelectAltimeter:
      gAltimeterSettingInHgInt = constrain(gAltimeterSettingInHgInt + cAltimeterSettingInHgInterval * increment, cAltimeterSettingInHgMin, cAltimeterSettingInHgMax);
      gEepromSaveNeededTs = millis();
      gNeedToWriteToEeprom = true;
      break;

    case CursorSelectMinimumsOn:
      if (gSensorMode != SensorModeOff) {
        gUpdateRightScreen = true;
        if (gMinimumsOn) {
          gMinimumsOn = false;
          gMinimumsSilenced = false;
        }
        else {
          gMinimumsOn = true;
          gMinimumsTriggered = false;
          gLastMinimumsAltitudeTs = millis(); //note the time the minimums altitude changed so we silence the alarm/buzzer for a short time
          gMinimumsSilenced = gMinimumsAltitudeLong > gTrueAltitudeDouble;
        }
      }
      break;

    case CursorSelectMinimumsAltitude:
    {
      gLastMinimumsAltitudeTs = millis(); //note the time the minimums altitude changed so we silence the alarm/buzzer for a short time

      int incrementMagnitude = cMinimumsSelectIncrement;
      int rounding = cMinimumsSelectIncrement;
      if (gLeftRotaryFineTuningPress) {
        incrementMagnitude = cAltitudeFineSelectIncrement;
        rounding = cAltitudeFineSelectIncrement;
      }
      else if (gMinimumsAltitudeLong % cMinimumsSelectIncrement != 0) {
        incrementMagnitude = cMinimumsSelectIncrement / 2; //we are at an in-between cMinimumsSelectIncrement state, so the knob movement will increment or decement to the nearest cAltitudeSelectIncrement
      }
      gMinimumsAltitudeLong = max(roundNumber(gMinimumsAltitudeLong + increment * incrementMagnitude, rounding), cLowestAltitudeSelect);
      if (gMinimumsAltitudeLong > cHighAltitude) {
        gMinimumsAltitudeLong = cHighAltitude;
      }

      //set the triggered flag
      gMinimumsTriggered = false;
      gMinimumsSilenced = gMinimumsAltitudeLong > gTrueAltitudeDouble;

      gEepromSaveNeededTs = millis();
      gNeedToWriteToEeprom = true; //save heading to EEPROM
      break;
    }

    case CursorSelectTimer:
      if (increment > 0 && gTimerStartTs == 0) {
        gTimerStartTs = millis() - 750;
      }
      else if (increment < 0) {
        gTimerStartTs = 0;
      }
      break;
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

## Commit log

2020-03-03 display changes, buzzer changes
    [altitude_heading_reminder.ino]
2020-03-06 Control of LCD brightness (this short-circuits the arduino)
    [altitude_heading_reminder.ino]
2020-03-08 fix to constrain() function call
    [altitude_heading_reminder.ino]
2020-03-12 permanent altitude offset calibration
2020-06-08 manuals and scade case model
    [PrototypeTop_V1.scad, PrototypeTop_V2.scad, Prototype_V1.scad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]
2020-06-22 feature: silenced alarm for short period of time after alarm goes off
    [altitude_heading_reminder.ino]
2020-06-23 bug fixes to flashing display
    [altitude_heading_reminder.ino]
2020-06-23 new case design and removing backlight flash logic
    [PrototypeTop_V3.scad, Prototype_V3.scad]
2020-06-23 PCB design files added
2020-06-24 PCB updates
2020-06-28 timer feature, moved version to splash screen, and updated temperature to Farenheit
2020-06-29 removed vertical speed, added piracy check, temperature in farenheit
2020-07-01 removed altitude and pressure units, updated OLED display logic
2020-07-02 custom libraries, inverted display option, display updates for OLED
    [altitude_heading_reminder.ino]
2020-07-06 buzzer and display updates
    [altitude_heading_reminder.ino]
2020-07-12 Datasheets, PCB, and schematic
2020-07-13 case and documentation updates
    [PrototypeTop_V1.scad, PrototypeTop_V2.scad, PrototypeTop_V3.scad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]
2020-07-13 Circuit Diagram & PCB updates
2020-07-19 altitude remaining feature, initial commit. adding TP4056 doc, and update to case model
    [PrototypeTop_V3.scad]
2020-07-20 Document Updates & Circuit Diagram Updates
    [Prototype_V3.scad]
2020-08-03 Battery level updates. Buzzer updates
    [altitude_heading_reminder.ino]
2020-08-07 circuit diagram update
2020-08-10 switch documentation
2020-08-21 circuit board and case updates
    [BOM_AltitudeHeadingReminder_2020-08-20_11-16-56.csv, BOM_AltitudeHeadingReminder_2020-08-20_22-47-56.csv, PickAndPlace_AltitudeHeadingReminder_PCB_2020-08-20_2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]
2020-08-24 schematic updates
2020-08-31 documentation and schematic updates
2020-09-07 documentation, schematic, PCB updates
2020-09-11 heading select bug fix. changed EEPROM write to 3 seconds
    [altitude_heading_reminder.ino]
2020-09-11 rearranging folder locations
    [PrototypeTop_V1.scad, PrototypeTop_V2.scad, PrototypeTop_V3.scad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]
2020-09-11 Schematic PCB updates
2020-09-11 case updates
    [PrototypeTop_V5.scad, Prototype_V5.scad]
2020-09-14 altitude display fixes, minimums functionality updates
    [altitude_heading_reminder.ino]
2020-09-19 PCB, circuit diagram, datasheets updates
2020-09-19 Minimums and battery logic
2020-09-19 battery update. storing minimums to EEPROM
2020-09-22 bug fixes related to pressure sensor failure or sensor mode being off
    [altitude_heading_reminder.ino]
2020-09-25 debug code for displaying battery voltage for battery testing
2020-10-01 battery debug readouts updated
2020-10-03 case, circuit diagram, and PCB updates
    [PrototypeTop_V6.scad, PrototypeTop_V6.stl, Prototype_V6.stl]
2020-10-03 PCB schematic updates
2021-02-07 case and schematic updates
    [PrototypeMountingPlate_V7.scad, PrototypeTop_V7.scad, Prototype_V7.scad]
2021-02-28 code updates - library updates needed for SPL06-007 sensor
2021-03-01 code updates, added image of bootloader wiring
2021-03-02 sensor mode update
2021-03-06 bug fix for "SILENT" displayed at start up
    [altitude_heading_reminder.ino]
2021-03-06 battery updates
2021-03-17 case and code updates
    [PrototypeMountingPlate_V8.scad, PrototypeTop_V8.scad, Prototype_V8.scad]
2021-03-17 removing old files
    [PrototypeMountingPlate_V7.stl, PrototypeTop_V7.stl, Prototype_V7.stl]
2021-03-23 display shifted
    [Prototype_V8.scad]
2021-03-23 removed snap joint for displays
    [Prototype_V8.scad]
2021-03-27 display pillar support case changes
    [Prototype_V11.scad]
2021-04-10 PCB and code updates
    [BOM_AltitudeHeadingReminderSchematic_2021-03-23.csv, BatteryVoltage.xlsx, PickAndPlace_AltitudeHeadingReminder_PCB_2021-03-23.csv]
